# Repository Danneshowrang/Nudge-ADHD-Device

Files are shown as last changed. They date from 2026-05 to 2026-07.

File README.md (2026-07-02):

# Nudge-ADHD-Device

## What is it
Nudge is a haptic feedback device made to combat ADHD-related time blindness. It does this by stimulating the user ever 15 minutes with a haptic effect.

## Why I made this project
I made this project because I, as an indivdual with ADHD who is heavily affected by time blindness, have missed a lot of opportunities, deadlines, and dates. (just now I missed the Stasis deadline to recieve a 150-point discount)
I hope that with this device, I, and others with ADHD, can create an artificial perception of time and live life with less regrets. 

## Future Plans
In the future I want to expand this device to not only be a Time-blindness solution, but an entire ADHD multitool. 
This means adding additional features such as calendar reminders, built-in focus timers, date countdowns, and a user-interactive display.

## Pictures






## CAD Link
Here is the link to the Onshape!
https://cad.onshape.com/documents/210c189d286efe197b4a566f/w/a50a3c19759326f033c6858b/e/ea3b0ad6e4c0592fd1c20846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

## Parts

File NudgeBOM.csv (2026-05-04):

Name | Price | Link
XIAO ESP32C3 | $4.99 | https://www.digikey.com/en/products/detail/seeed-technology-co-ltd/113991054/16652880
DRV2605L Haptic Driver | $3.45 | https://www.digikey.com/en/products/detail/texas-instruments/DRV2605LDGST/5023854
LRA Haptic Motor | $3.13 | https://www.digikey.com/en/products/detail/jie-yi-electronics-limited/JYLRA1040ZF/20193257
Push Button | $0.30 | https://www.digikey.com/en/products/detail/panasonic-industry/EVQ-P7C01P/4429449
1.5A LiPo Battery | $13.08 | https://www.digikey.com/en/products/detail/mikroelektronika/MIKROE-4473/13679425
 |  | "+ shipping"
 | $24.95 | $29.94

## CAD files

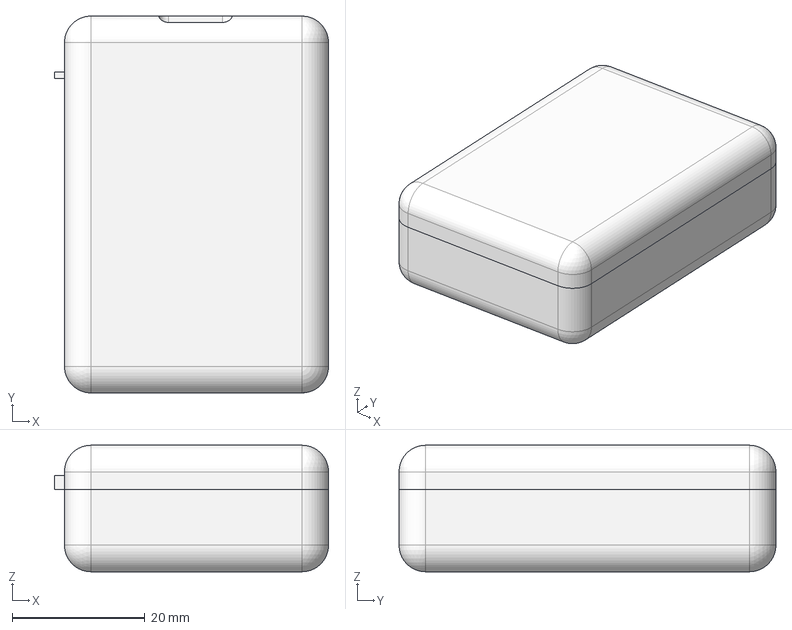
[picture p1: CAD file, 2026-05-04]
Nudge Complete.step
41.3 x 56.8 x 19.1 mm
BOSS-EXTRUDE14_7_
BOSS-EXTRUDE7_2_
Seeed Studio XIAO-ESP32-C3 v15
BOSS-EXTRUDE7_1_
BOSS-EXTRUDE7_4_
MIRROR2
C_0805_2012Metric x 2
BOSS-EXTRUDE7_9_
Battery Model
U.FL Connector v1 x 3
BOSS-EXTRUDE14_11_
BOSS-EXTRUDE14_8_
SW_SPST_EVQP7A
BOSS-EXTRUDE14_10_
BOSS-EXTRUDE7_8_
BOSS-EXTRUDE14_5_
BOSS-EXTRUDE14_12_
BOSS-EXTRUDE7_3_
Lid
BOSS-EXTRUDE7_7_
Button (1)_1
BOSS-EXTRUDE14_3_
BOSS-EXTRUDE7_6_
Nudge_PCB
BOSS-EXTRUDE7_5_
BOSS-EXTRUDE14_1_
VSSOP-10_3x3mm_P0.5mm
BOSS-EXTRUDE14_9_
BOSS-EXTRUDE14_2_
Button (1)
BOSS-EXTRUDE14_4_
CUT-EXTRUDE5
Shield
BOSS-EXTRUDE14_6_

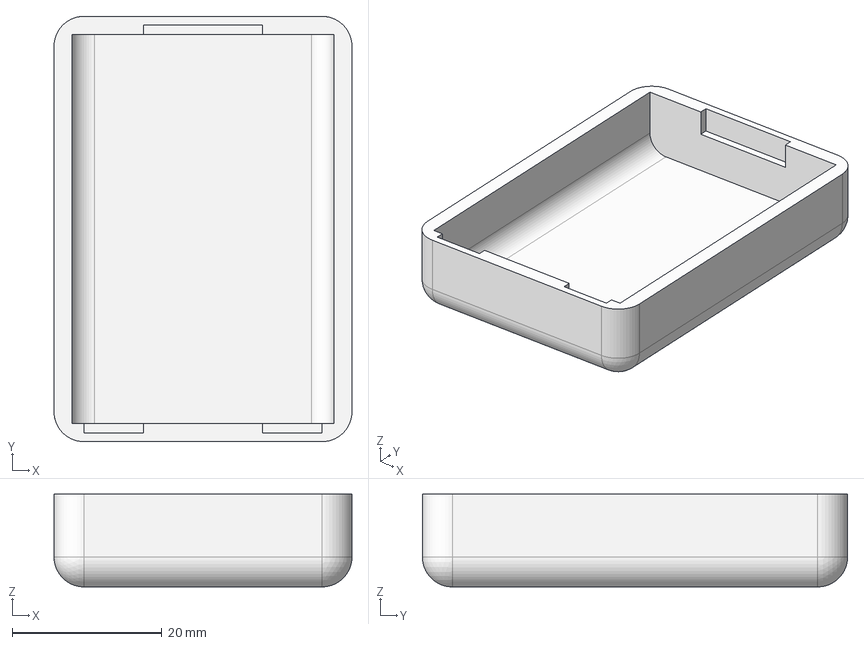
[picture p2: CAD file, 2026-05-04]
Nudge - Body.step
39.8 x 56.8 x 12.4 mm

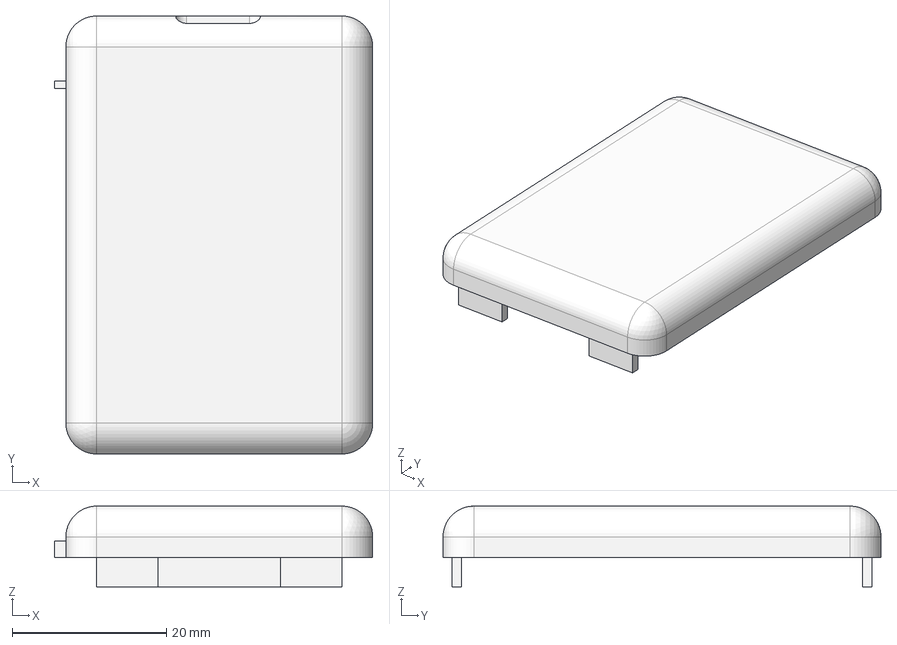
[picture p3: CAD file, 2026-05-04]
Nudge - Lid.step
41.3 x 56.8 x 10.5 mm

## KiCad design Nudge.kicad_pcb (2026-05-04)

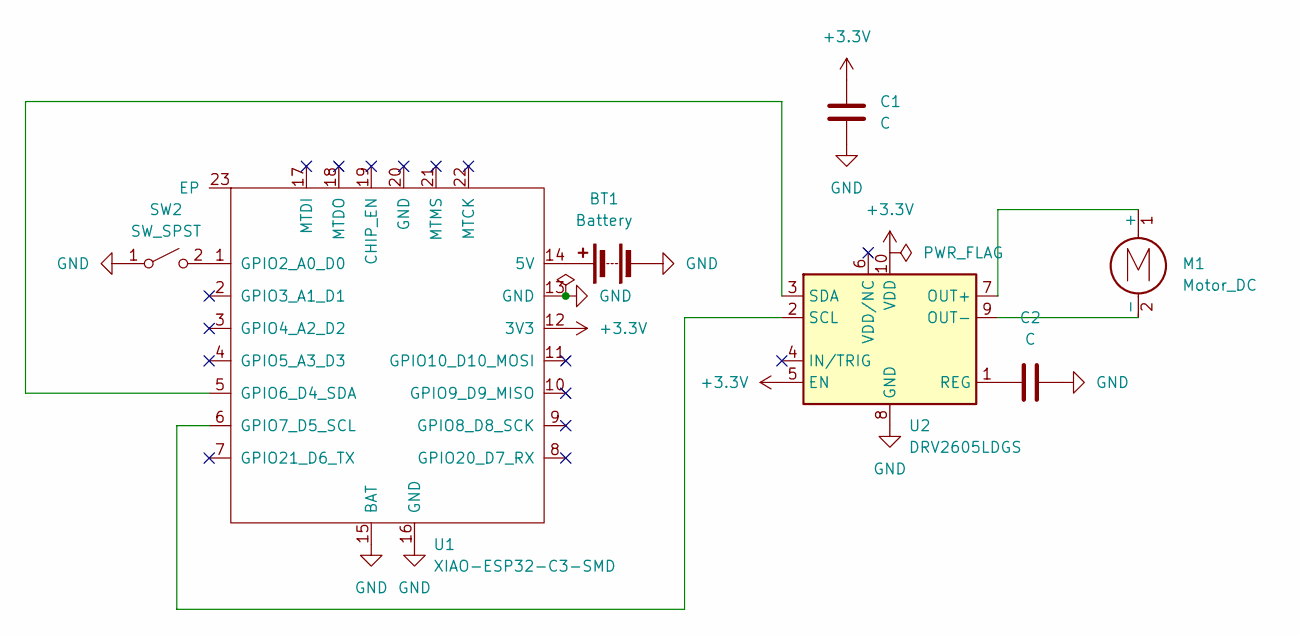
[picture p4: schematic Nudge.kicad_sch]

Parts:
BT1: Battery; SolderWire-0.5sqmm_1x02_P4.6mm_D0.9mm_OD2.1mm_Relief
C1, C2: C; C_0805_2012Metric
M1: Motor_DC; SolderWire-0.5sqmm_1x02_P4.6mm_D0.9mm_OD2.1mm_Relief
SW2: SW_SPST; SW_SPST_EVQP7A
U1: XIAO-ESP32-C3-SMD; MCU_Seeed_ESP32C3
U2: DRV2605LDGS; VSSOP-10_3x3mm_P0.5mm

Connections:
+3.3V: C1.1, U1.12 (3V3), U2.5 (EN), U2.10 (VDD)
GND: BT1.2 (-), C1.2, C2.2, SW2.1 (A), U1.13 (GND), U1.15 (BAT), U1.16 (GND), U2.8 (GND)
unnamed: BT1.1 (+), U1.14 (5V)
unnamed: M1.1 (+), U2.7 (OUT+)
unnamed: M1.2 (-), U2.9 (OUT-)
unnamed: SW2.2 (B), U1.1 (GPIO2_A0_D0)
unnamed: U1.5 (GPIO6_D4_SDA), U2.3 (SDA)
unnamed: U1.6 (GPIO7_D5_SCL), U2.2 (SCL)
unnamed: C2.1, U2.1 (REG)

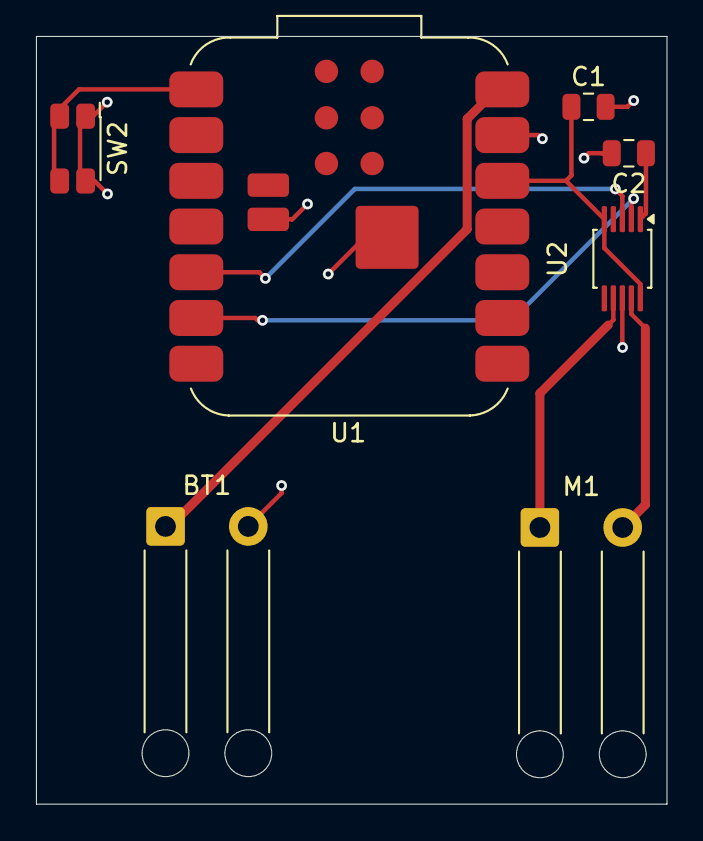
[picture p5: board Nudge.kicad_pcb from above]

Board: 4 copper layers, 35.0 x 42.7 mm, 7 parts (0 on the bottom side), 9 nets.

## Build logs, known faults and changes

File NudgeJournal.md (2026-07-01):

<!--
  This journal is auto generated by Stasis.
-->

# 5/4/2026 4 AM - Haptic & Web Server programming

_Time spent: 2h_

May 3

Firstly, I configured the platformIO environment and configured the SDA and SCL pins, set GPIO2 to act as the sleep toggle, and then initialized the DRV2605 library.





I then created a web server UI where I can select which haptic effect the device will be outputting



This UI is pretty unintuitive and is only for bare-bones usage. In the future, I want to make it user-friendly and add time control too.

Lastly, I added the sleep feature. Now, the device should leave sleep every 15 minutes, buzz, then go back into deep sleep.





# 5/4/2026 2 AM - Second CAD

_Time spent: 2.25h_

Apr. 29

Today I made a revised version of the case.



I reduced the wall thickness from 6 mm to 2.4 mm, which forced me to remove the built-in doweling, which forced me to make a notch/groove system so that the parts can be press-fit.

I also widened the slotting for the USB-C port so that a cable can fit through the case. 

I also made the button more compliant.



Here is how the final CAD looks assembled. 



You might think that it looks bulky, but it is .75 inches thick, which is around the same as a roll of pennies.





# 5/4/2026 12 AM - First CAD

_Time spent: 2h_

Apr. 28

Today was my birthday! Unfortunately, I have a pretty bad sinus infection, so I went to San Antonio to visit a doctor.

On the way, I made a housing for the device. 



The most annoying part was the button.



When I was designing this part, I was heavily influenced by a random youtube short that I couldnt find to link here. Basically, the short explained that in order for 3D-printed buttons to stay firm and limit unwanted movement, the button should be connected to the body by small tabs on the sides. 

In my feverish state, I tried to make something like this that would be printed seperately for replacability. If you look at it though, you can kinda tell that its probably going to be way too stiff to actually work well. Also, I made the wall thickness of the device 6mm, which according to later google research, is probably super overkill. I want the device to not feel like a toy though, so i'll have to change that later.

I also added built-in doweling so that I can press-fit the lid into the case over the pcb.

Look at the USB-C slot, and you can see that the original slot is too small and won't allow a cable to be plugged in.



So, with all these problems identified, I will correct them with my next iteration.





# 5/4/2026 12 AM - PCB Design

_Time spent: 6h_

Apr. 25

I finished the layout and ran the Design Rules Checker, and then fixed the actual functional errors that would mess up the manufacturing, but I ignored the silkscreen warnings because they don't affect how the board works. The majority of my time went to routing everything correctly, since some of the ratsnest lines were not the same as my schematics lines, I had to adjust the schematic to correct the differences.



Technical Fixes & DRC Results

Edge Clearances: My SW2 switch was too close to the board edge. The DRC flagged it because I only had 0.4550 mm of space, and the rule required 0.5000 mm, so I moved it inwards slightly.

Via Cleanup: I had two ground vias sitting in the exact same spot. The checker flagged them as "co-located," so I found the stack and deleted the extra one.

Silkscreen Warnings: The labels for the ESP32-C3 (U1) and DRV2605L (U2) were hanging off the edge. Since this is just ink and won't cause a short or a failure, I left them as-is. 

I also made the power lines for the battery and motor thicker than the signal lines to handle the current without heating up.

Now that the layout is done, the unrouted count is 0, and the functional errors are cleared. I will CAD the casing.



# 5/3/2026 11 PM - Schematic Design!

_Time spent: 6h_

Apr. 23

Today, I spent a few hours in KiCad drafting the wiring schematic. Since im a beginner, it took a bit of time figuring out where to route each signal and understanding the net logic required for the MCU to communicate with the peripherals. My initial attempt to manually route wires from point to point was proven unfeasible because of the risk of signal noise, so I pivoted to a 4-layer PCB.



Short Circuits: I accidentally connected the battery power directly to the ground. If I hadn't caught that in the software, the 1.5Ah battery would have shorted out immediately.

Floating Pins: I left the EN pins disconnected. I learned that you can't just leave pins pins floating, and that they need to be tied to a specific voltage (3.3V) or the chip won't know whether to turn on or stay off.

The 3.3V Trace: I initially thought I needed a whole layer for power, but I realized I could just route 3.3V as a normal trace since my ground plane was taking up the bulk of the space for heat management.

Power Dips: I added capacitors (C1 and C2) because I learned that when the motor kicks on, it can suck out enough power to reset the entire board, so the capacitors can make sure that this doesn't happen.

Now that the schematic is done, the next thing to do is design the PCB!



# 5/3/2026 10 PM - Hardware preparation and selection

_Time spent: 4.25h_

Apr. 19th

Today I chose all the hardware I was going to use for this project.

Firstly, spent some time time researching the ESP32-S3 versus the ESP32-C3. While the S3 is a powerhouse, its more than I need and would affect my battery life. So, instead, I am going to use the ESP-32C3. It’s much smaller, which helps with the devices actual size, and its deep-sleep power consumption is exactly what I need to keep the internal clock running while the rest of the board sleeps. 



However, the C3 has a thermal belly pad, so I wouldnt be able to solder it conventionally. I will probably need to use a hot plate and do some reflow soldering.

For the haptics, after doing some research, I found that most normal vibration motors have a muddied feel, so, for user experience, I am going to LRA haptic motor along with the DRV2605L haptic driver, which has a built-in library of effects and patterns and can control the haptic motor precisely.

The biggest pivot of the day, however, was the battery. I initially looked at a tiny 110mAh LiPo to keep things sleek, but after doing the math, I found that there was a safety issue. Standard charging chips like the TP4056 output 1A by default, which is 45 times the 22mAh charge rate of the 110 mAh LiPo! I want this to be THE BOMB and not A BOMB, so I’ve decided to go with a 1500mAh (1.5Ah) LiPo battery.

Next, i'll make my wiring schematic on KiCAD.



# 4/27/2026 4 AM - Initial Planning & Requirements for The Nudge

_Time spent: 3h_

Apr. 17

   If you have ADHD, you have probably been affected by "time blindness" more than a few times. For my neurotypical brothers out there, time blindness is the difficulty with perceiving, estimating, and managing time. It causes chronic lateness, the underestimating of task times, and crazy procrastination (for more information, you can read about it [here](https://add.org/adhd-time-blindness/).) I want to make an ESP-32-powered accessory that can help "nudge" me and oathers back into the real world. 

Since my AP's are coming up and I have a crazy amount of self-studying to do, I toggled an accesibility feature on my laptop to verbally announce the time every fifteen minutes. However, since it is a audibly announced, it sometimes does not register in my head and I lose track of time again. I want my device to be more subtle, but have a more potent effect. So, my device should stimulate the user every so often to give them a passive perception of the time. 



To do this, I have decided to aim for a pocket-sized vibrating device that buzzes in a custom time interview. The device should be light, have a good battery life, and generate a noticable simulus. Also, I am thinking of leveraging the full potential of such a device by making it multifunctional. I could utilize diferent vibration patterns or strengths to indicate different things. For example, a hydration reminder could be a heavy, one second vibration, while the regular time reminder could be a short small chirp.

I made a small sketch on what the device would look like and what features I want on it. 



No. 1 - Vibration Motor

I want to use a vibration motor vs. a speaker or something similar because they are relatively quiet but also provides a physical stimulus to really pull me down to earth.

No. 2 - Battery

The device obviously has to be portable, and to keep power, it needs a good internal battery that can last a convenient amount of time.

No. 3 - Clean Build

I want the device to be visually clean so I wont be stuck with an eyesore in my every day life.

No. 4 - Button for sleep

This one is very important. Since I want to keep a good battery life as well as interact with the device without plugging into the USB-C port, turning off the bluetooth, WiFi, and haptic feedback when I am sleeping or do not need it is a really great way to cut down on the power consumption. However, I cannot just turn off the board since I need the ESP-32's clock to be accurately calibrated. So, this sleep button would turn off the main functions of the device while keeping the internal clock running.

No. 5 - WiFi for configuring

When I want to configure the buzzes times, patterns, and frequencies, as well as recalibrate the clock in the case of the battery completely dying, I want to be able to connect to the device on an online portal and update it.

No. 6 - Quiet Haptic Feedback

As I mentioned before, I want the buzzes to only be felt by the user that has the device in their pocket, as to avoid distracting other people or drawing uneccesary attention. So, the quieter the vibration motor I can find, the better.

No. 7 - Pocket Sized

The device should fit in the user's pocket with ease and be lightweight.

No. 8 - Sturdy

As someone who drops their phone a lot, I want the device to be as sturdy and drop-resistant as possible to avoid damage. Somewhat related, I usually lose track of time in the shower and if I could somehow make the product water-resistant then that would be great.




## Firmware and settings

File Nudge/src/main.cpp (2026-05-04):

#include <Arduino.h>
#include <Wire.h>
#include <WiFi.h>
#include <WebServer.h>
#include "esp_sleep.h"
#include "Adafruit_DRV2605.h"

#define SLEEP_PIN GPIO_NUM_2
#define SDA_PIN 6
#define SCL_PIN 7

Adafruit_DRV2605 drv;
WebServer server(80);
int effectID = 1;

void hapticEffect(int id){
  drv.setWaveform(0, id);
  drv.setWaveform(1, 0);
  drv.go();
}

void setup(){
  Serial.begin(115200);
  pinMode(SLEEP_PIN, INPUT_PULLUP);

  Wire.begin(SDA_PIN, SCL_PIN);
  if (!drv.begin()){
    Serial.println("DRV Failed");
    while (1);
  }
  drv.selectLibrary(1);
  drv.setMode(DRV2605_MODE_INTTRIG);

  if(esp_sleep_get_wakeup_cause() == ESP_SLEEP_WAKEUP_EXT0){
    hapticEffect(effectID);
  }

  WiFi.softAP("Nudge_config", "passwordpassword");
  server.on("/", [](){
    String html = "<h1>Settings</h1><p>Current Effect: " + String(effectID) + "</p>";
    html += "<form action='/s'>New ID (1-123): <input name='v'><input type='submit'></form>";
    server.send(200, "text/html", html);
  });
  server.on("/s", [](){
    if (server.hasArg("v")) effectID = server.arg("v").toInt();
    server.send(200, "text/html", "Updated. <a href='/'>Back</a>");
  });
  server.begin();

  esp_deep_sleep_enable_gpio_wakeup(1 << SLEEP_PIN, ESP_GPIO_WAKEUP_GPIO_LOW);
  
  esp_sleep_enable_timer_wakeup(15 * 60 * 1000000);

  esp_deep_sleep_start();
  
}

void loop(){
  server.handleClient();

  if(millis() > 30000){
    Serial.println("Sleep");
    esp_deep_sleep_start();
  }
}

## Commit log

2026-05-04 Add Nudge.kicad_pcb file
    [Nudge.kicad_pcb]
2026-07-02 Add CAD link to README
    Added a link to the Onshape CAD document.
